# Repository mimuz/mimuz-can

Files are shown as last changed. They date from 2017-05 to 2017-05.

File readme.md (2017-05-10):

# mi:muz:can

mimuz-can logo

`mi:muz-can` and variations are small boards for build easier to midi instrument that sounds cans using with push solenoid.

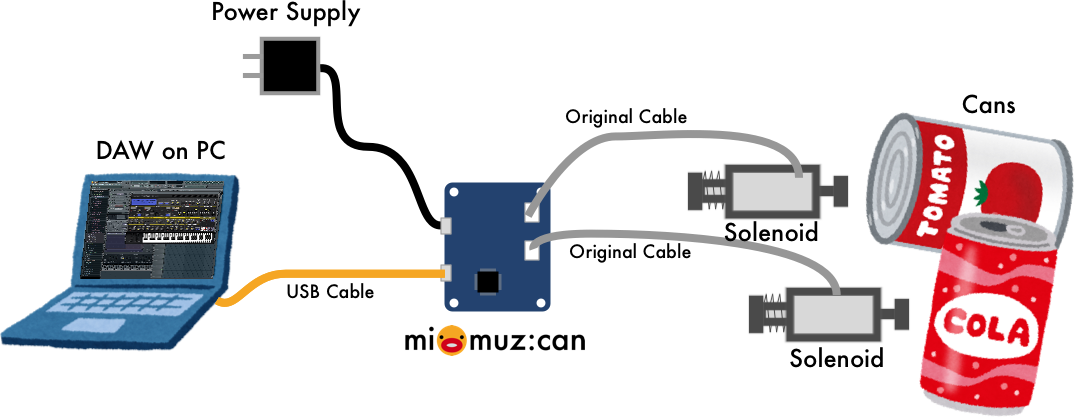
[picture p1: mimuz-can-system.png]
mimuz-can-system


The following variations are exist:

## In Production

- [mi:muz:can (Standard Version)](./mimuz-can): "mi:muz:can" is a board for build easier to USB-MIDI instrument that sounds up to 6 cans using with push solenoid. For using powerful electric current, It has 2.1mm DC Jack for 12V DC Power supply.
- [mi:muz:can-lite](./mimuz-can-lite): "mi:muz:can-lite" is a board for build easier to USB-MIDI instrument that sounds up to 2 cans using with push solenoid. This is a "simple for use" version, It has micro-B usb connector for using USB charger for smartphone/tablet.

## demo

- [1st demo (YouTube)](https://youtu.be/6YQHXj_-I3c)

## Solenoids

All of the mi:muz:can devices are now only support the following 5V PUSH type solenoids:

- [Sparkfun Solenoid - 5v (small) (ROB-11015)](https://www.sparkfun.com/products/11015)
- [ZHO-0420S-05A4.5(5V)](http://akizukidenshi.com/catalog/g/gP-10761/)

## Licenses

- [Licences for mi:muz:can](./mimuz-can/LICENSE.md)
- [Licences for mi:muz:can-lite](./mimuz-can-lite/LICENSE.md)

## [Previous draft versions (Arduino versions)](./draft)

Previous draft versions (Arduino versions) are for experimental use versions made with [Arduino UNO Rev.3](https://store.arduino.cc/arduino-uno-rev3), [Ardiono Leonardo](https://www.arduino.cc/en/main/arduinoBoardLeonardo) and [mi:muz:expr#1](https://github.com/mimuz/mimuz-avr-core/tree/master/boards/expr1).

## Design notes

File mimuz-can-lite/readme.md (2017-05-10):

# mi:muz:can-lite

mimuz-can logo

"mi:muz:can-lite" is a board for build easier to USB-MIDI instrument that sounds up to 2 cans using with push solenoid. This is a "simple for use" version, It has micro-B usb connector for using USB charger for smartphone/tablet.

## Version

- v0.10 (2017.05.10)

## Eagle Files

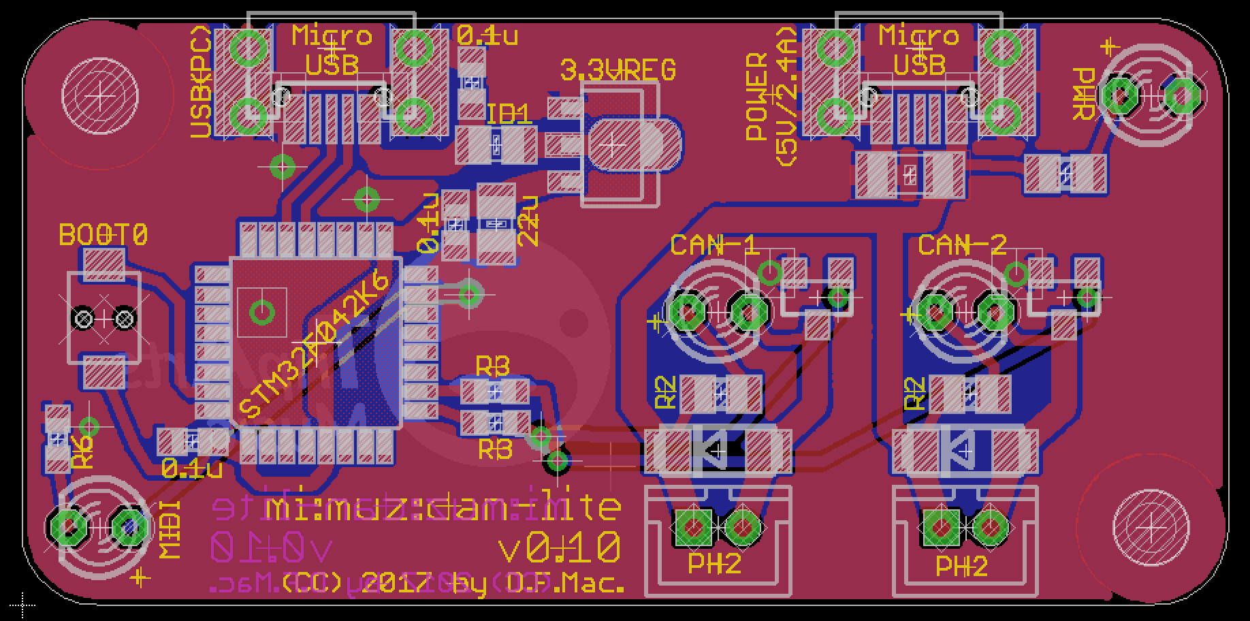
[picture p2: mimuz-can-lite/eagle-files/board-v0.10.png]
board


[eagle files (v0.10)](./eagle-files/v0.10)

## parts

- [STM32F042K6T6](http://www.st.com/content/st_com/ja/products/microcontrollers/stm32-32-bit-arm-cortex-mcus/stm32f0-series/stm32f0x2/stm32f042k6.html) * 1
- [HT7333-A (3.3V regulator) SOT89-3](http://www.holtek.com.tw/documents/10179/116711/HT73xx-1v100.pdf) * 1
- [Ferrite beads (0805)](http://akizukidenshi.com/catalog/g/gP-04054/) * 1 [ID1]
- 470Ω(0603) * 1 (For USB DATA LED)
- 1kΩ(0603) * 2 (For FET gate line)
- 1.5kΩ(0805) * 1 (For Power LED)
- 3mLED * 4 
- 0.1uF(0603) * 3
- 22uF(0805) * 1
- 47uF(1206 25V) * 1
- [Tactical Switch (2 points SMT)](http://www.aitendo.com/product/10525) * 1
- [micro USB Connector](https://www.aliexpress.com/item/Free-shipping-100pcs-lot-4-feet-DIP-5P-SMD-Micro-USB-Connector-V8-Port-Charge-Socket/32214653369.html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) * 2
- PH2.0 2P Connector * 2
- 1N5819(DO214AC SMD) Shotkey diode * 2
- IRLML6344TRPBF SOT23 (Nch Mosfet) * 2

## Firmware

- [Source](../mimuz-can/source)
- [bin](./bin)

### Firmware Setup 

1. Install [SW4STM32](http://www.st.com/content/st_com/ja/products/development-tools/software-development-tools/stm32-software-development-tools/stm32-ides/sw4stm32.html)
2. Install DFU Loader (i.e. dfu-util see [dfu-util - Device Firmware Upgrade Utilities](http://dfu-util.sourceforge.net/))
3. Copy [Source](./source/mimuz-tuch) to your workspace path and select build target `mimuz-can-lite` and Bulding it. When your build process is succeed, `mimuz-can-lite.bin` is created in `./mimuz-can-lite/` folder.
4. push and hold mi:muz:can-lite board switch'BOOT0' switch and connect to USB Port. After connection, you can release switch. `mi:muz:can-lite` board will startup in DFU mode. 
5. Burn [mimuz-can-lite.bin] using DFU Loader. On Mac, enter the following command on terminal in same mimuz-can-lite.bin path.

> `dfu-util -a0 -d 0x0483:0xdf11 -s 0x008000000 -D mimuz-can.bin`

# Licenses

## Hardware (Schematics, Board, Eagle files), Software (Application, USB-MIDI Class Driver)

- [Creative Commons Attribution 4.0 International (CC BY 4.0)](http://creativecommons.org/licenses/by/4.0/)

## Software (STMCube from ST Microsystems)

- 3-clause BSD license

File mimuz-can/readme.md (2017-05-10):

# mi:muz:can (Standard Version)

mimuz-can logo

"mi:muz:can" is a board for build easier to USB-MIDI instrument that sounds up to 6 cans using with push solenoid. For using powerful electric current, It has 2.1mm DC Jack for 12V DC Power supply.

## Version

- v0.30 (2017.05.10)

## Eagle Files

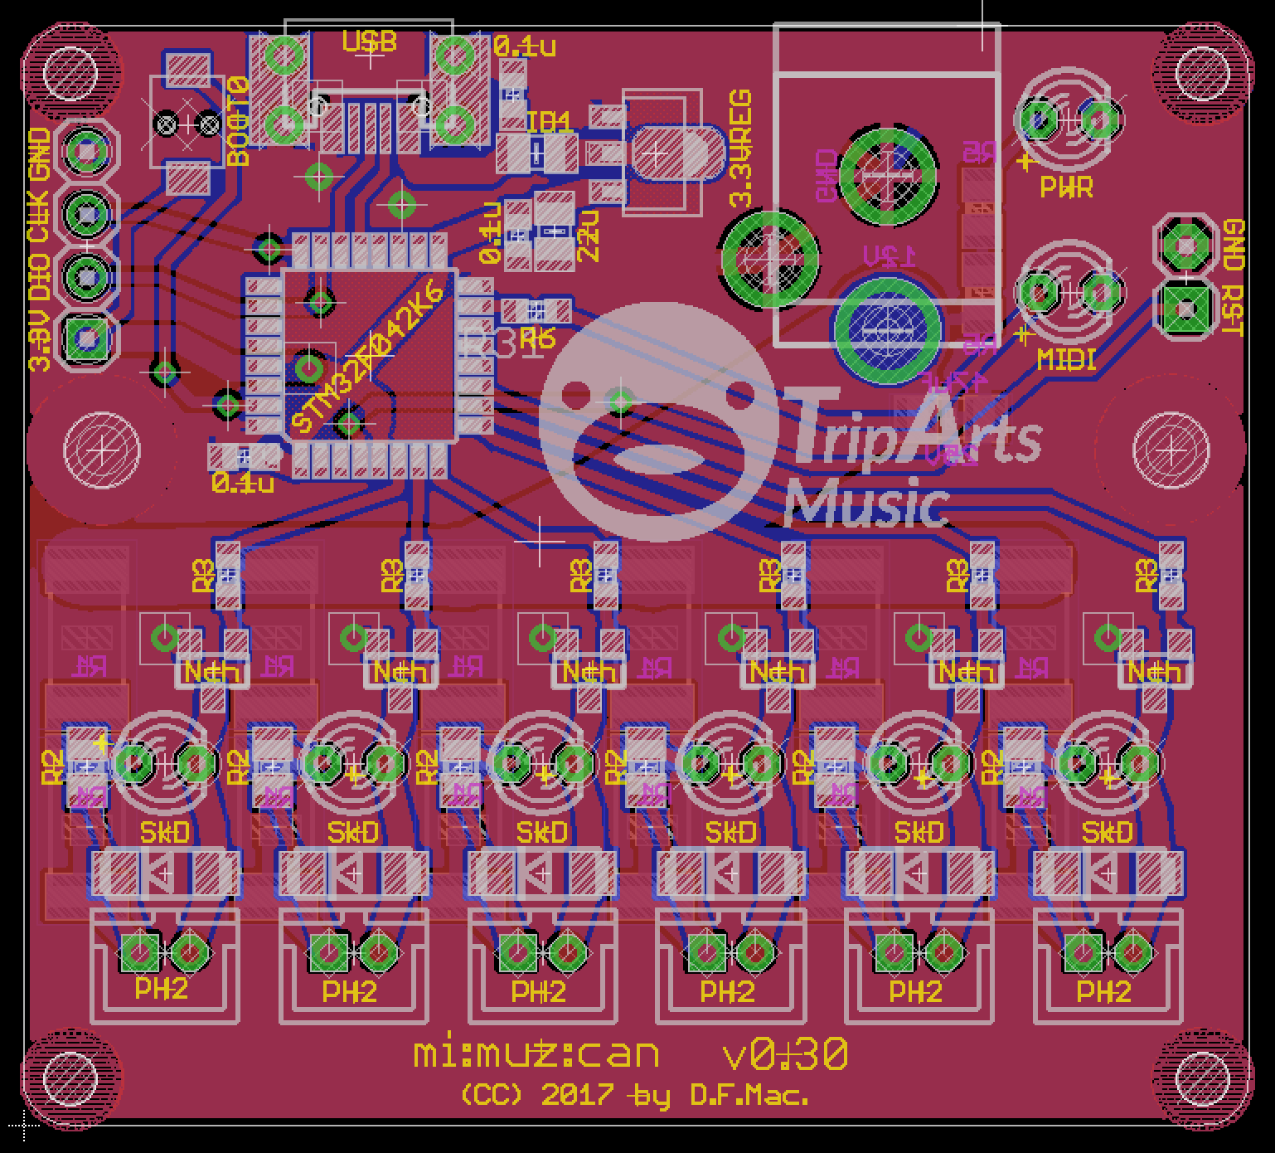
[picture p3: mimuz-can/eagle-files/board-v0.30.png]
board


[eagle files (v0.30)](./eagle-files/v0.30)

## parts

- [STM32F042K6T6](http://www.st.com/content/st_com/ja/products/microcontrollers/stm32-32-bit-arm-cortex-mcus/stm32f0-series/stm32f0x2/stm32f042k6.html) * 1
- [HT7333-A (3.3V regulator) SOT89-3](http://www.holtek.com.tw/documents/10179/116711/HT73xx-1v100.pdf) * 1
- [Ferrite beads (0805)](http://akizukidenshi.com/catalog/g/gP-04054/) * 1 [ID1]
- 470Ω(0603) * 1 (For USB DATA LED)
- 1kΩ(0603) * 6 (For FET gate line)
- 1.5kΩ(0805) * 1 (For Power LED)
- 2.2kΩ(0805) * 1 (For Power LED)
- 8.2Ω(2512 1W) * 12 (For Solenoid Line)
- 3mLED * 8 
- 0.1uF(0603) * 3
- 22uF(0805) * 1
- 47uF(1206 25V) * 1
- [Tactical Switch (2 points SMT)](http://www.aitendo.com/product/10525) * 1
- [micro USB Connector](https://www.aliexpress.com/item/Free-shipping-100pcs-lot-4-feet-DIP-5P-SMD-Micro-USB-Connector-V8-Port-Charge-Socket/32214653369.html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) * 1
- [2.1mm DC Jack](http://akizukidenshi.com/catalog/g/gC-06568/) * 1
- PH2.0 2P Connector * 6
- 1N5819(DO214AC SMD) Shotkey diode * 6
- IRLML6344TRPBF SOT23 (Nch Mosfet) * 6

## Firmware

- [Source](./source)
- [bin](./bin)

### Firmware Setup 

1. Install [SW4STM32](http://www.st.com/content/st_com/ja/products/development-tools/software-development-tools/stm32-software-development-tools/stm32-ides/sw4stm32.html)
2. Install DFU Loader (i.e. dfu-util see [dfu-util - Device Firmware Upgrade Utilities](http://dfu-util.sourceforge.net/))
3. Copy [Source](./source/mimuz-tuch) to your workspace path and select build target `mimuz-can` and Bulding it. When your build process is succeed, `mimuz-can.bin` is created in `./mimuz-can/` folder.
4. push and hold mi:muz:can board switch'BOOT0' switch and connect to USB Port. After connection, you can release switch. `mi:muz:can` board will startup in DFU mode. 
5. Burn [mimuz-can.bin] using DFU Loader. On Mac, enter the following command on terminal in same mimuz-can.bin path.

> `dfu-util -a0 -d 0x0483:0xdf11 -s 0x008000000 -D mimuz-can.bin`

# Licenses

## Hardware (Schematics, Board, Eagle files), Software (Application, USB-MIDI Class Driver)

- [Creative Commons Attribution 4.0 International (CC BY 4.0)](http://creativecommons.org/licenses/by/4.0/)

## Software (STMCube from ST Microsystems)

- 3-clause BSD license

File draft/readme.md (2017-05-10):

# mi:muz:can previous draft versions (Arduino versions)

mimuz-can logo

# 1. mi:muz:expr#1 Version

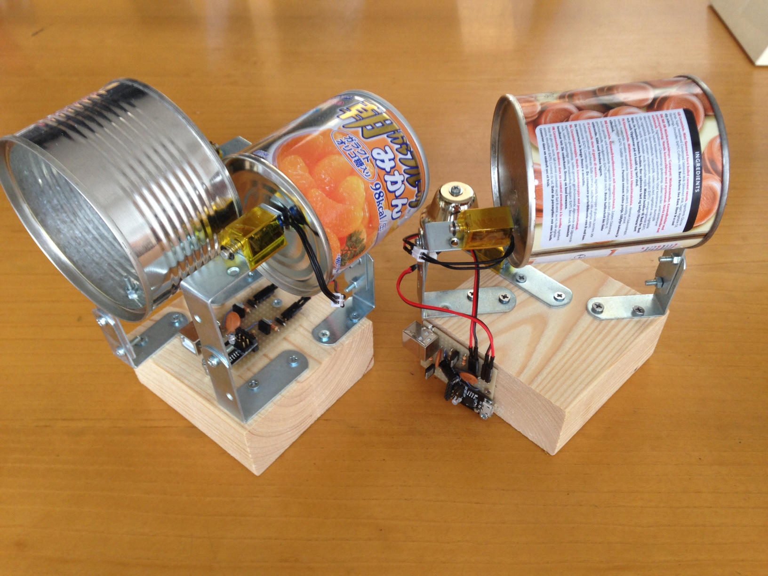
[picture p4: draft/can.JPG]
can attacker


[Maker Faire Tokyo 2015](http://makezine.jp/event/makers2015/d_f_mac_at_triparts_music/)で展示したものです。
[mi:muz:expr#1](https://github.com/tadfmac/mi-muz/tree/master/boards/expr1)ベースで作ったものです。

mi:muz:expr#1は、LEDに利用しているPB3を除くと、PB1とPB4の2つしか空きポートがありません。
これら２つのポートにそれぞれMOSFET、ソレノイドを1つづつ接続して2つの缶を叩くデバイスを作りました。

## Version

v1.0 (2015.08.25)

## Schematics

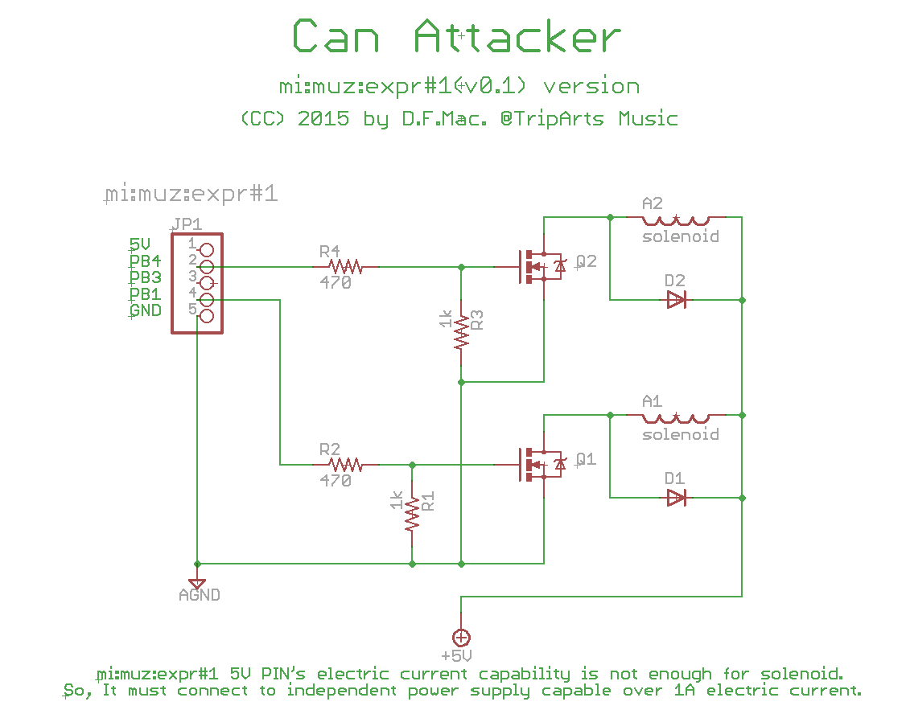
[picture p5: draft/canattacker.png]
can attacker mi:muz:expr#1 version


## parts

- JP1: mi:muz:expr#1
- R1: 1kΩ
- R2: 470Ω
- R3: 1kΩ
- R4: 470KΩ
- Q1/Q2: [2SK4017](http://akizukidenshi.com/catalog/g/gI-07597/)
- D1/D2: 1N4007
- A1/A2: [5V Push Solenoid　ROB-11015](https://www.sparkfun.com/products/11015)

## Firmware

[Firmware](./can1_mimuz-expr1/can1_mimuz-expr1.ino)

# 2. Arduio UNO Version

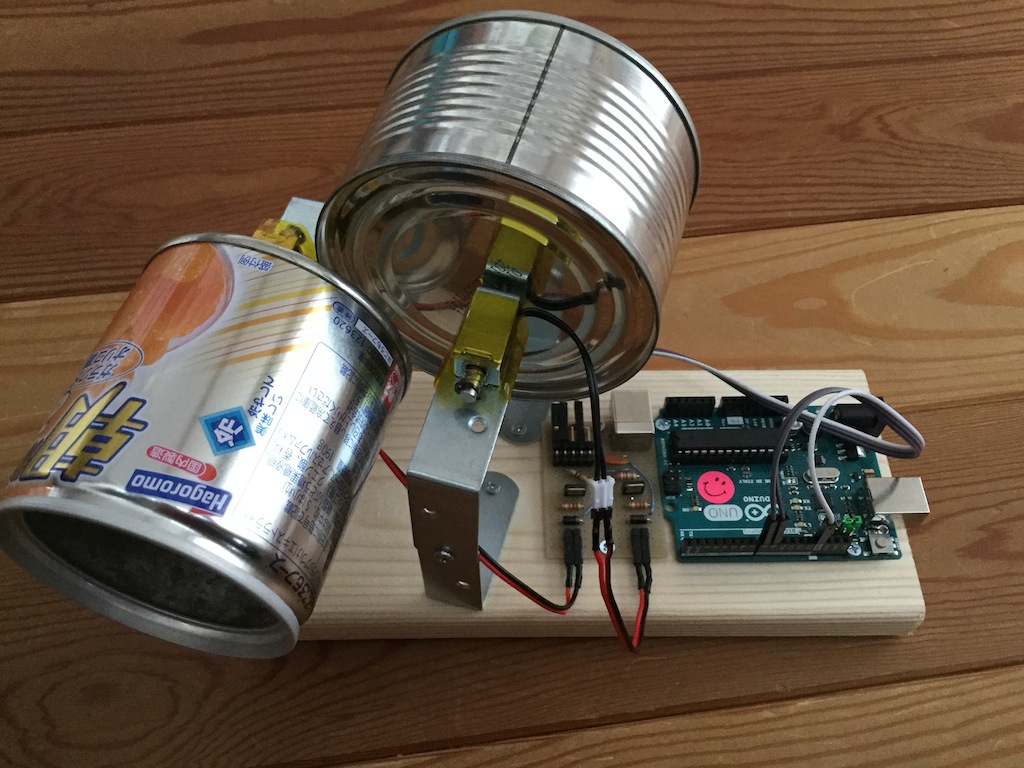
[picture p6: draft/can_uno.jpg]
can attacker Arduino UNO Version


Arduino UNOでも作ってみました。

## Dependencies

Arduino UNOでUSB-MIDIを扱うために、[Arduino MIDI Library](http://playground.arduino.cc/Main/MIDILibrary)と、@morecat_labさん作[mocoLUFA](https://github.com/kuwatay)を利用させて頂いています。

## Version

v1.0 (2015.08.30)

## Schematics

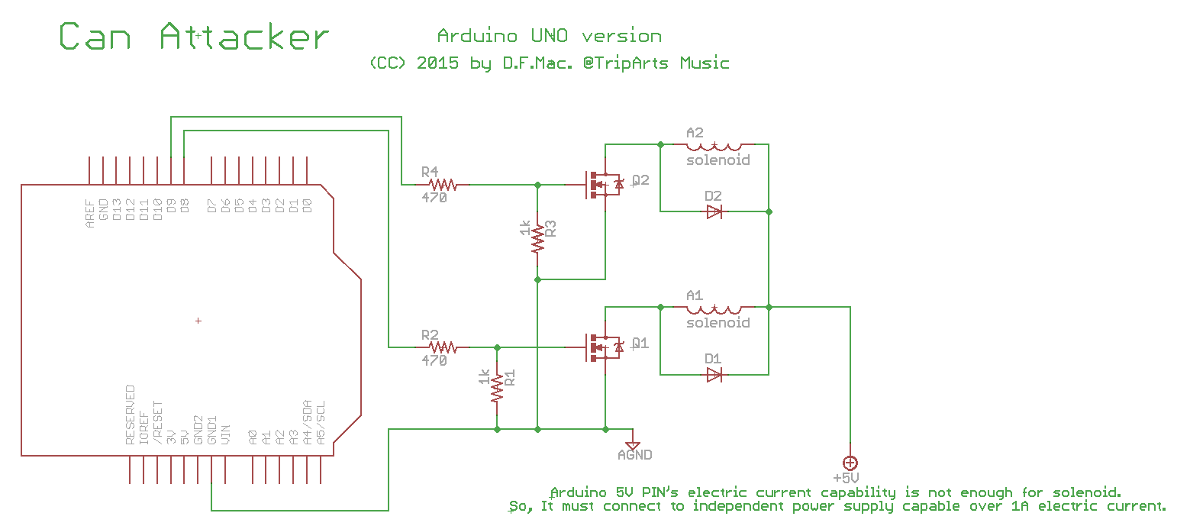
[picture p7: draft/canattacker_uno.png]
can attacker Arduino UNO version


## parts

- Arduino UNO Rev.3
- R1: 1kΩ
- R2: 470Ω
- R3: 1kΩ
- R4: 470KΩ
- Q1/Q2: [2SK4017](http://akizukidenshi.com/catalog/g/gI-07597/)
- D1/D2: 1N4007
- A1/A2: [5V Push Solenoid　ROB-11015](https://www.sparkfun.com/products/11015)

## Firmware

[Firmware](./can2_uno/can2_uno.ino)

----

# 3. Arduino Leonardo Version

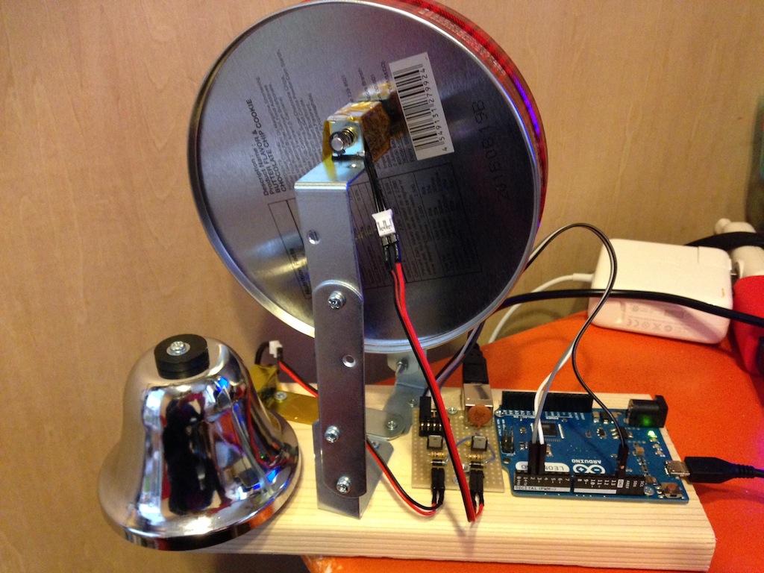
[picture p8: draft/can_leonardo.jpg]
can attacker Arduino Leonardo Version


Arduino Leonardoでも作ってみました！！！！

## Dependencies

Arduino LeonardoをUSB-MIDIに対応させるため、[rkistner/arcore](https://github.com/rkistner/arcore)を利用させて頂きました！

利用方法は、[こちら](http://qiita.com/tadfmac/items/d685dae3e46d570386c3)を参照ください。

## Version

v1.0 (2015.11.25)

## Schematics

配線はArduino UNOバージョンとほぼ同じです。
ただし、下記のように変更しています。

|Arduino UNO Version|Arduino Leonardo Versionでの変更点|
|:----|:---:|
|PIN8|PIN2|
|PIN9|PIN3|

※スケッチがそうなっているというだけで、基本的にお好きなデジタル端子に繋げば大丈夫です。

## parts

- Arduino Leonardo
- R1: 100kΩ (変更してみました)
- R2: 470Ω
- R3: 100kΩ (変更してみました)
- R4: 470KΩ
- Q1/Q2: [IRLU3410PBF](http://akizukidenshi.com/catalog/g/gI-06025/) (2SK4017がどっか行ったので)
- D1/D2: 1N4007
- A1/A2: [5V Push Solenoid　ROB-11015](https://www.sparkfun.com/products/11015)

## Firmware

[Firmware](./can4_leonardo/can4_leonardo.ino)

# Licenses

<br />この 作品 は <a rel="license" href="http://creativecommons.org/licenses/by/4.0/">クリエイティブ・コモンズ 表示 4.0 国際 ライセンスの下に提供されています。</a>

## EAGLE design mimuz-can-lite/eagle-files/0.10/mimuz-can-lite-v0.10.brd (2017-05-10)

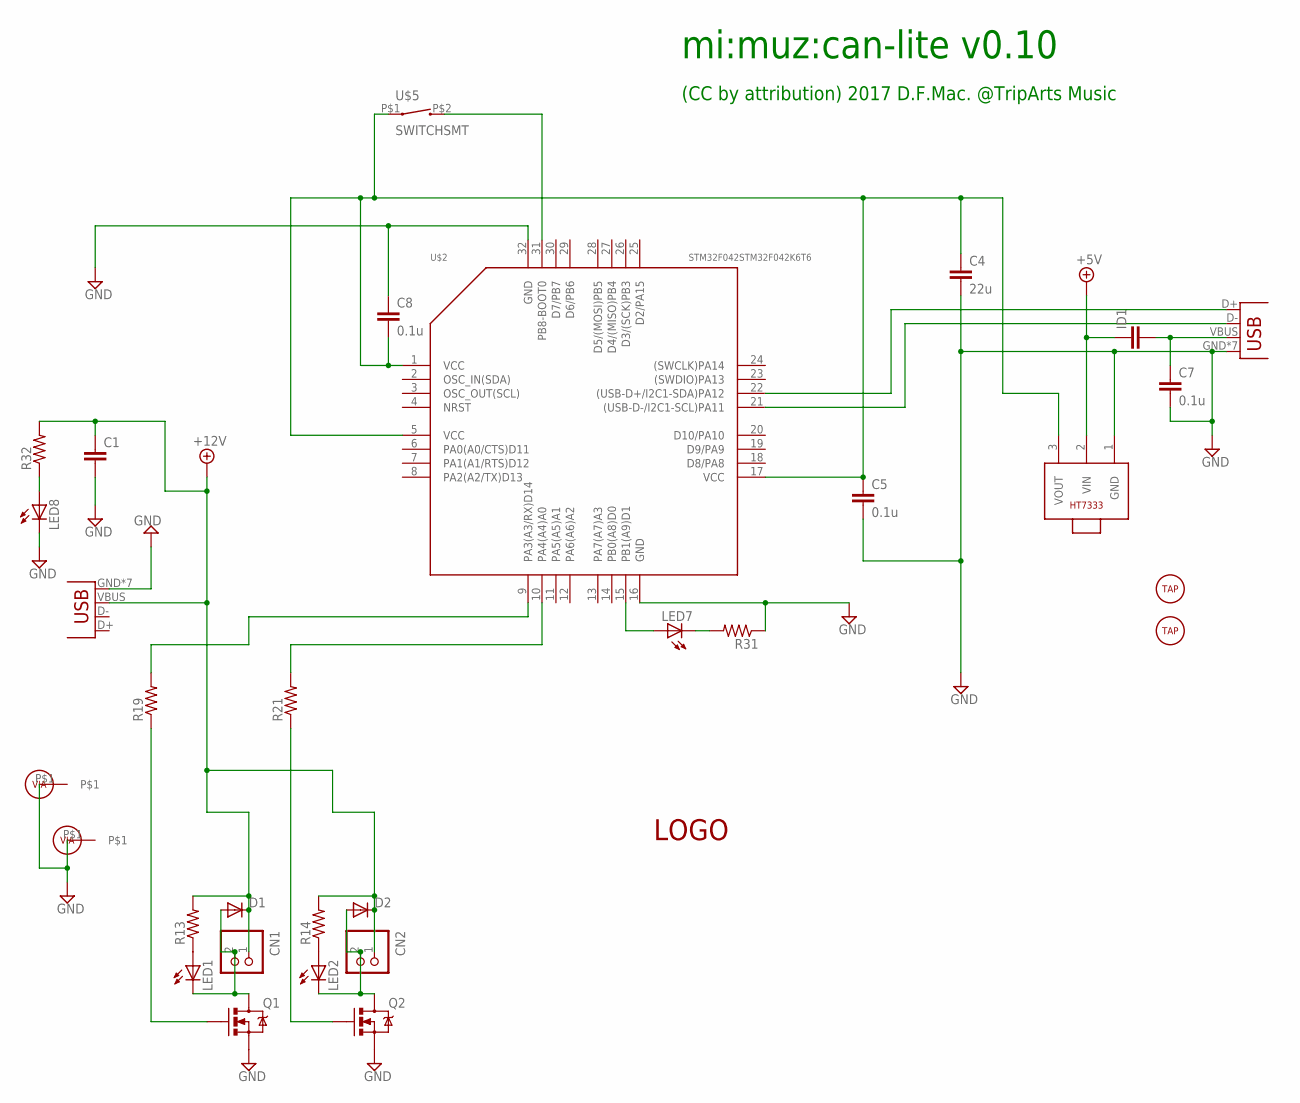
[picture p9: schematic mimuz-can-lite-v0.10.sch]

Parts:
C1: C-EUC1206; C1206
C4: 22u; C0805
C5, C7, C8: 0.1u; C0603
CN1, CN2: B2B-PH-K-S
D1, D2: DIODE-DO214AC; DO214AC
ID1: C-EUC0805; C0805
JP3, JP4: USB-MICROB
LED1, LED2, LED7, LED8: LED3MM
Q1, Q2: MOSFET-NCHANNELSMD; SOT23-3
R13, R14, R32: R-US_R0805; R0805
R19, R21, R31: R-US_R0603; R0603
U$1: LOGOSMALL; LOGO-SMALL
U$2: STM32F042STM32F042K6T6; TQFP32
U$3, U$6: TAPHOLE; TAPHOLE-3MM
U$4, U$7: VIA
U$5: SWITCHSMT; SWITCH-SMT-2*4*3
U$14: HT7333; SOT89

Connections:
3.3V: C4.1, C5.1, C8.2, U$2.1 (VCC), U$2.5 (VCC), U$2.17 (VCC), U$5.P$1 (1), U$14.3 (VOUT)
+5V: ID1.1, U$14.2 (VIN)
+5V2: C1.1, CN1.1, CN2.1, D1.C, D2.C, JP3.VBUS, R13.2, R14.2, R32.2
D+: JP4.D+, U$2.22 ((USB-D+/I2C1-SDA)PA12)
D-: JP4.D-, U$2.21 ((USB-D-/I2C1-SCL)PA11)
GND: C1.2, C4.2, C5.2, C7.2, C8.1, JP3.GND, JP3.MT1 (GND), JP3.MT3 (GND), JP3.P$2 (GND), JP3.P$4 (GND), JP3.P$5 (GND), JP3.P$6 (GND), JP4.GND, JP4.MT1 (GND), JP4.MT3 (GND), JP4.P$2 (GND), JP4.P$4 (GND), JP4.P$5 (GND), JP4.P$6 (GND), LED8.K (C), Q1.2 (S), Q2.2 (S), R31.1, U$2.16 (GND), U$2.32 (GND), U$4.P$1, U$7.P$1, U$14.1 (GND)
unnamed: LED7.A, U$2.15 (PB1(A9)D1)
unnamed: LED7.K (C), R31.2
unnamed: CN1.2, D1.A, LED1.K (C), Q1.3 (D)
unnamed: CN2.2, D2.A, LED2.K (C), Q2.3 (D)
unnamed: LED1.A, R13.1
unnamed: LED2.A, R14.1
unnamed: Q2.1 (G), R21.1
unnamed: Q1.1 (G), R19.1
unnamed: U$2.31 (PB8-BOOT0), U$5.P$2 (2)
unnamed: R19.2, U$2.9 (PA3(A3/RX)D14)
unnamed: R21.2, U$2.10 (PA4(A4)A0)
unnamed: LED8.A, R32.1
VBUS: C7.1, ID1.2, JP4.VBUS

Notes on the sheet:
mi:muz:can-lite v0.10
(CC by attribution) 2017 D.F.Mac. @TripArts Music

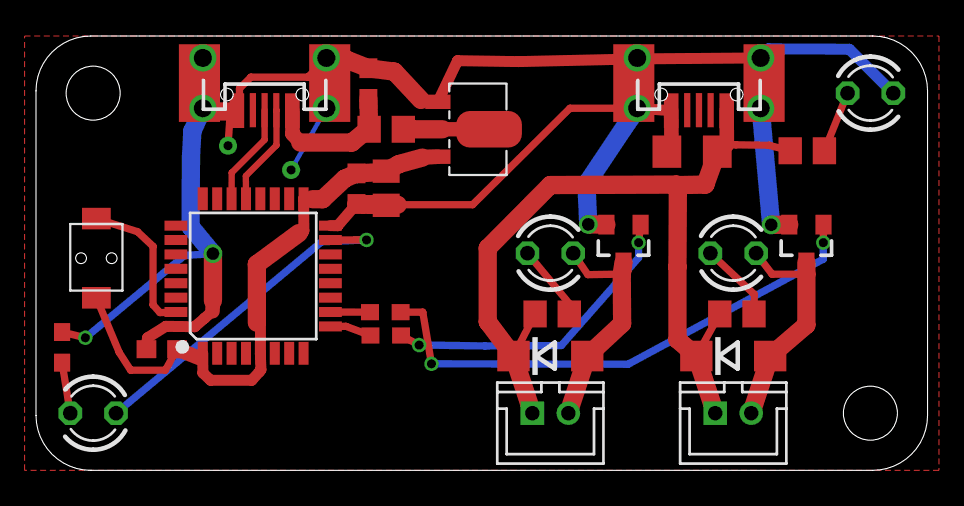
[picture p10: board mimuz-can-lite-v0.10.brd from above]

Board: 2 copper layers, 49.5 x 24.1 mm, 32 parts (1 on the bottom side), 19 nets.

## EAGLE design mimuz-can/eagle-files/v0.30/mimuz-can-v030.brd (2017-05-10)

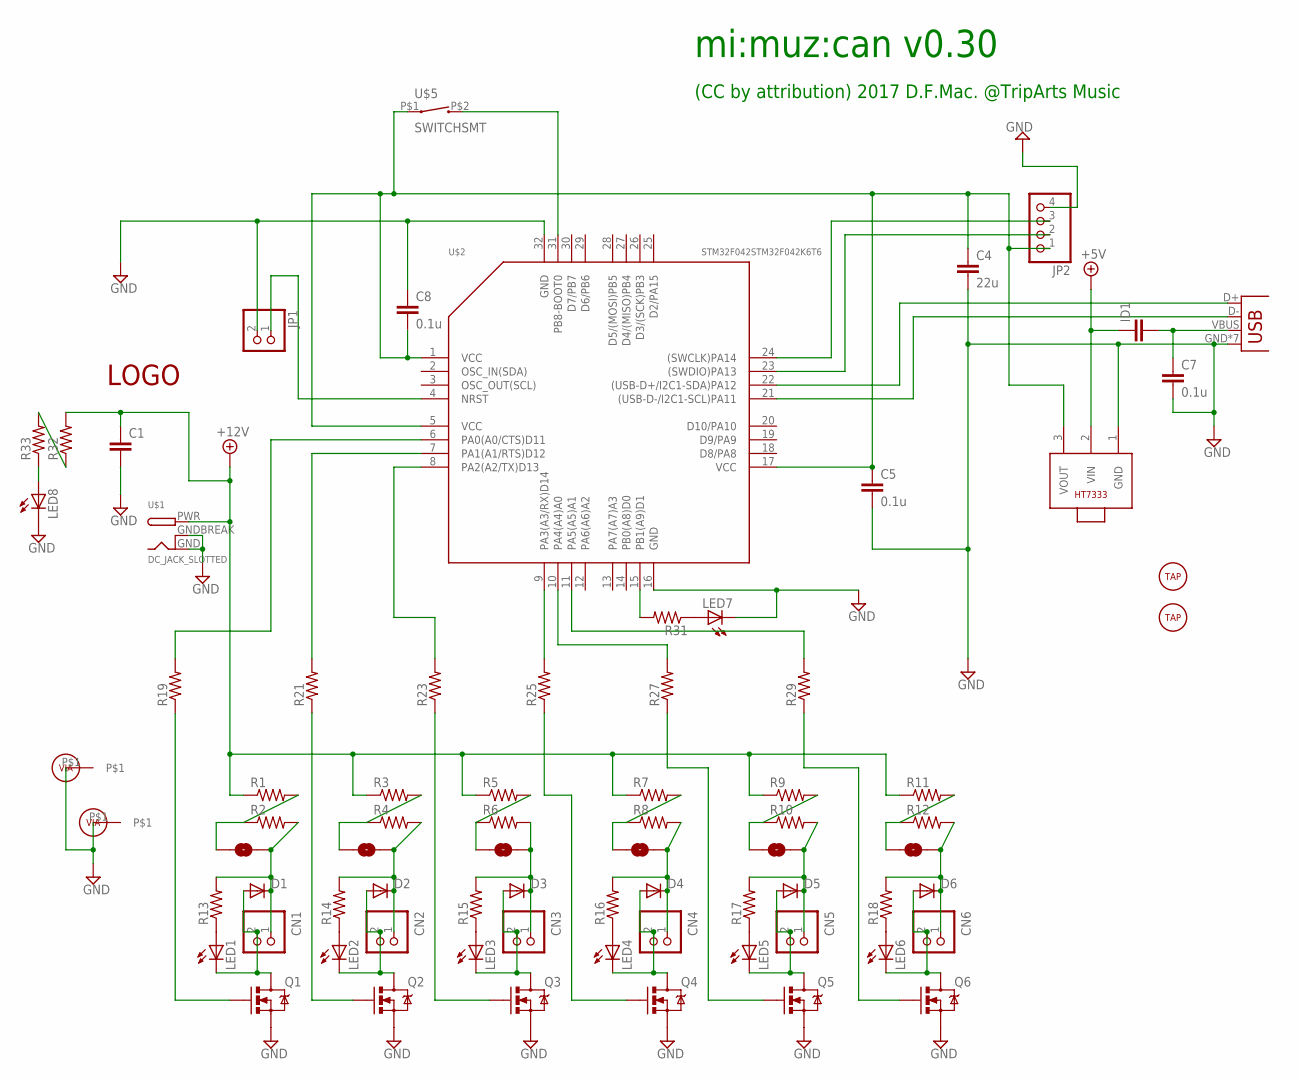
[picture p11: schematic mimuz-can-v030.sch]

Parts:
C1: C-EUC1206; C1206
C4: 22u; C0805
C5, C7, C8: 0.1u; C0603
CN1, CN2, CN3, CN4, CN5, CN6: B2B-PH-K-S
D1, D2, D3, D4, D5, D6: DIODE-DO214AC; DO214AC
ID1: C-EUC0805; C0805
JP1: PINHD-1X2; 1X02
JP2: PINHD-1X4; 1X04
JP3, JP5, JP6, JP7, JP8, JP9: JUMPER-SMT_2_NO_NO-SILK; SMT-JUMPER_2_NO_NO-SILK
JP4: USB-MICROB
LED1, LED2, LED3, LED4, LED5, LED6, LED7, LED8: LED3MM
Q1, Q2, Q3, Q4, Q5, Q6: MOSFET-NCHANNELSMD; SOT23-3
R1, R2, R3, R4, R5, R6, R7, R8, R9, R10, R11, R12: R-US_R2512; R2512
R13, R14, R15, R16, R17, R18, R32, R33: R-US_R0805; R0805
R19, R21, R23, R25, R27, R29, R31: R-US_R0603; R0603
U$1: DC_JACK_SLOTTED
U$2: STM32F042STM32F042K6T6; TQFP32
U$3, U$6: TAPHOLE; TAPHOLE-3MM
U$4, U$7: VIA
U$5: SWITCHSMT; SWITCH-SMT-2*4*3
U$12: LOGOSMALL; LOGO-SMALL
U$14: HT7333; SOT89

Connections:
3.3V: C4.1, C5.1, C8.2, JP2.1, U$2.1 (VCC), U$2.5 (VCC), U$2.17 (VCC), U$5.P$1 (1), U$14.3 (VOUT)
+5V: ID1.1, U$14.2 (VIN)
+12V: C1.1, R1.1, R3.1, R5.1, R7.1, R9.1, R11.1, R32.2, U$1.PWR
D+: JP4.D+, U$2.22 ((USB-D+/I2C1-SDA)PA12)
D-: JP4.D-, U$2.21 ((USB-D-/I2C1-SCL)PA11)
GND: C1.2, C4.2, C5.2, C7.2, C8.1, JP1.2, JP2.4, JP4.GND, JP4.MT1 (GND), JP4.MT3 (GND), JP4.P$2 (GND), JP4.P$4 (GND), JP4.P$5 (GND), JP4.P$6 (GND), LED7.K (C), LED8.K (C), Q1.2 (S), Q2.2 (S), Q3.2 (S), Q4.2 (S), Q5.2 (S), Q6.2 (S), U$1.GND, U$1.GNDBREAK, U$2.16 (GND), U$2.32 (GND), U$4.P$1, U$7.P$1, U$14.1 (GND)
unnamed: JP5.1, R3.2, R4.1
unnamed: JP3.1, R1.2, R2.1
unnamed: JP6.1, R5.2, R6.1
unnamed: CN1.1, D1.C, JP3.2, R2.2, R13.2
unnamed: CN2.1, D2.C, JP5.2, R4.2, R14.2
unnamed: CN3.1, D3.C, JP6.2, R6.2, R15.2
unnamed: CN1.2, D1.A, LED1.K (C), Q1.3 (D)
unnamed: CN2.2, D2.A, LED2.K (C), Q2.3 (D)
unnamed: CN3.2, D3.A, LED3.K (C), Q3.3 (D)
unnamed: JP7.1, R7.2, R8.1
unnamed: CN4.1, D4.C, JP7.2, R8.2, R16.2
unnamed: CN4.2, D4.A, LED4.K (C), Q4.3 (D)
unnamed: CN5.2, D5.A, LED5.K (C), Q5.3 (D)
unnamed: CN6.2, D6.A, LED6.K (C), Q6.3 (D)
unnamed: JP8.1, R9.2, R10.1
unnamed: JP9.1, R11.2, R12.1
unnamed: LED1.A, R13.1
unnamed: CN6.1, D6.C, JP9.2, R12.2, R18.2
unnamed: CN5.1, D5.C, JP8.2, R10.2, R17.2
unnamed: LED2.A, R14.1
unnamed: LED3.A, R15.1
unnamed: LED4.A, R16.1
unnamed: Q2.1 (G), R21.1
unnamed: Q1.1 (G), R19.1
unnamed: LED5.A, R17.1
unnamed: Q3.1 (G), R23.1
unnamed: JP2.3, U$2.24 ((SWCLK)PA14)
unnamed: JP2.2, U$2.23 ((SWDIO)PA13)
unnamed: JP1.1, U$2.4 (NRST)
unnamed: U$2.31 (PB8-BOOT0), U$5.P$2 (2)
unnamed: LED6.A, R18.1
unnamed: R19.2, U$2.6 (PA0(A0/CTS)D11)
unnamed: R21.2, U$2.7 (PA1(A1/RTS)D12)
unnamed: R23.2, U$2.8 (PA2(A2/TX)D13)
unnamed: R27.2, U$2.10 (PA4(A4)A0)
unnamed: R25.2, U$2.9 (PA3(A3/RX)D14)
unnamed: Q4.1 (G), R25.1
unnamed: Q5.1 (G), R27.1
unnamed: R29.2, U$2.11 (PA5(A5)A1)
unnamed: Q6.1 (G), R29.1
unnamed: R31.2, U$2.15 (PB1(A9)D1)
unnamed: LED7.A, R31.1
unnamed: R32.1, R33.2
unnamed: LED8.A, R33.1
VBUS: C7.1, ID1.2, JP4.VBUS

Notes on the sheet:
mi:muz:can v0.30
(CC by attribution) 2017 D.F.Mac. @TripArts Music

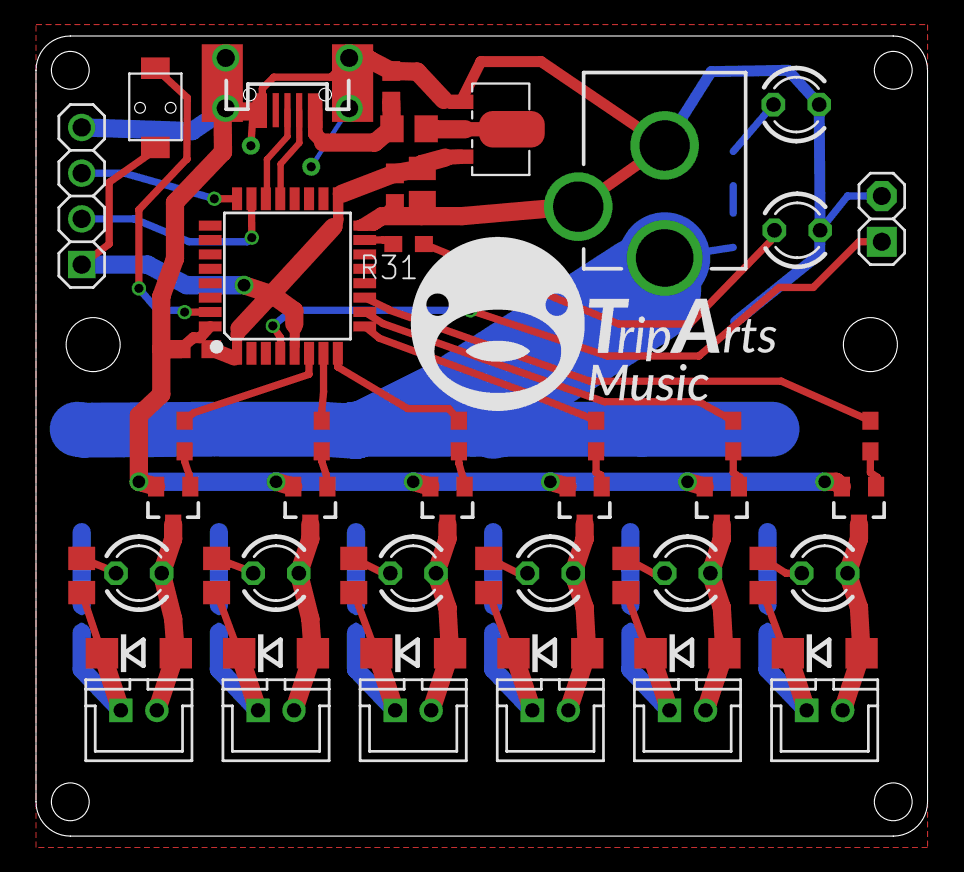
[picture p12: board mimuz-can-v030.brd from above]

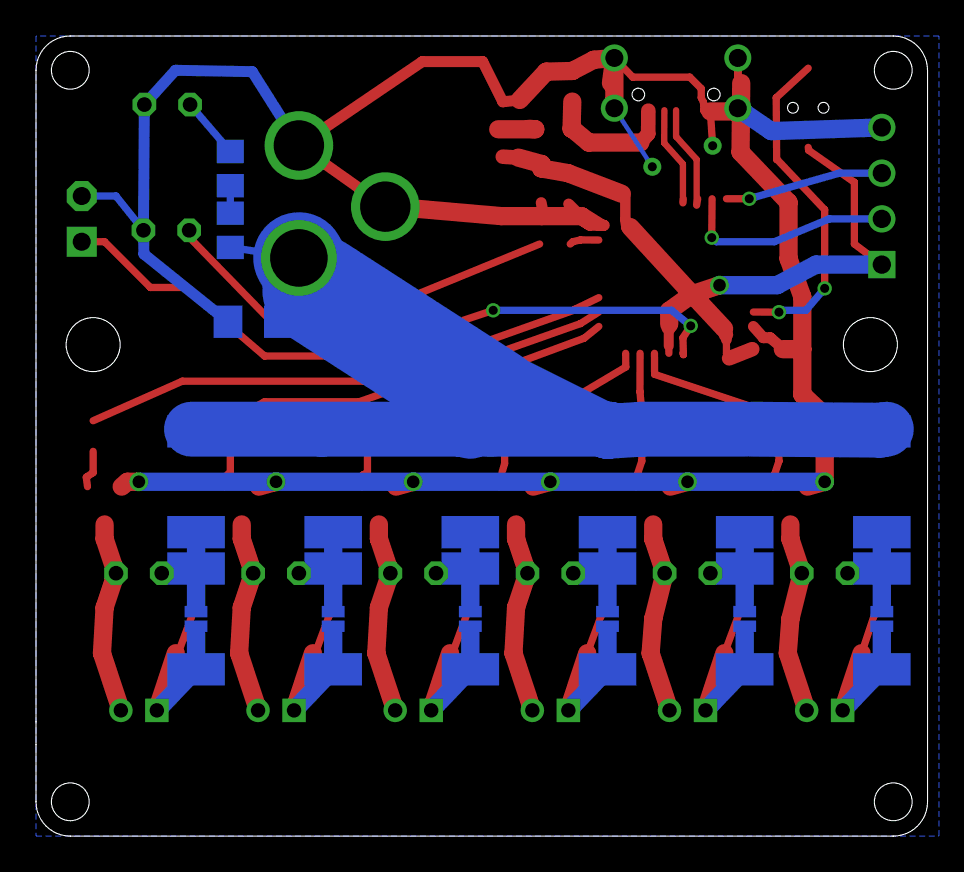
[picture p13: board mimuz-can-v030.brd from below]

Board: 2 copper layers, 49.5 x 44.5 mm, 77 parts (21 on the bottom side), 51 nets.

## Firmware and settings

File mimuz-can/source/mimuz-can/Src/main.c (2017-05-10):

//
// mi:muz:can v0.20
//
//  (CC at)2017 by D.F.Mac. @TripArts Music
//
//
// PIN Configuration
//
// PA0 : CAN OUT #1  (OUT)
// PA1 : CAN OUT #2  (OUT)
// PA2 : CAN OUT #3  (OUT)
// PA3 : CAN OUT #4  (OUT)
// PA4 : CAN OUT #5  (OUT)
// PA5 : CAN OUT #6  (OUT)
// PB1 : LED (OUT)
// PA8 : N/A
// PA9 : N/A
// PA10: N/A
// PA11: USB D-
// PA12: USB D+
// PA13: SWDIO
// PA14: SWCLK
// PA15: N/A
// PB3 : N/A
// PB4 : N/A
// PB5 : N/A
// PB6 : N/A
// PB7 : N/A
// PB8 : BOOT0
// PF0 : N/A
// PF1 : N/A

#include "stm32f0xx_hal.h"
#include "usb_device.h"
#include "usbd_midi_if.h"
#include "eeprom.h"
#include "main.h"

// Can GPIO Table
TCanGPIO tCanGpio[CAN_CHANNELS]={
  {GPIOA, GPIO_PIN_0},
  {GPIOA, GPIO_PIN_1},
  {GPIOA, GPIO_PIN_2},
  {GPIOA, GPIO_PIN_3},
  {GPIOA, GPIO_PIN_4},
  {GPIOA, GPIO_PIN_5} 
};

// EEPROM
uint16_t VirtAddVarTab[NB_OF_VAR] = {
  0x1000, 0x1001, 0x1002, 0x1003,
  0x1004, 0x1005, 0x1006, 0x1007
};

uint16_t VarDataTab[NB_OF_VAR] = {0, 0, 0, 0, 0, 0, 0, 0};

// MIDI
int val[] = {0,0,0,0,0,0};

//uint8_t notes[] = {36,38,40,43,45,48}; // C2 D2 E2 G2 A2 C3
uint8_t notes[] = {60,62,64,67,69,72}; // C4 D4 E4 G4 A4 C5
int onoff[] = {0,0,0,0,0,0};

uint16_t ledTime = 0;

void debug_led(int times){
  int cnt;
  while(1){
    for(cnt = 0;cnt < times;cnt ++){
      HAL_GPIO_WritePin(GPIOB, GPIO_PIN_1, GPIO_PIN_SET);
      HAL_Delay(200);
      HAL_GPIO_WritePin(GPIOB, GPIO_PIN_1, GPIO_PIN_RESET);
      HAL_Delay(200);
    }
    HAL_Delay(1000);
  }
}

int debug_status = 0;


void led_on(void){
  ledTime = LEDTIMEMAX;
  HAL_GPIO_WritePin(GPIOB, GPIO_PIN_1, GPIO_PIN_SET);
}

void led_off(void){
  ledTime = 0;
  HAL_GPIO_WritePin(GPIOB, GPIO_PIN_1, GPIO_PIN_RESET);
}

static void onNoteOn(uint8_t ch, uint8_t note, uint8_t vel){
  int canNumber;
  led_on();

  canNumber = getNoteCh(note);
  if(canNumber != -1){
	  if(vel != 0){
	    onoff[canNumber] = CAN_TIMEBASE + (CAN_TIMESTEP * vel);
	    CanStart(canNumber);
	  }
  }
}

static void onNoteOff(uint8_t ch, uint8_t note, uint8_t vel){
}


static int getNoteCh(uint8_t noteNum){
  int cnt;
  for(cnt=0;cnt<CAN_CHANNELS;cnt++){
    if(notes[cnt] == noteNum){
      return cnt;
    }
  }
  return -1;
}

uint8_t mode = 0; // 0: none 1: write 2: read

static void onCtlChange(uint8_t ch, uint8_t num, uint8_t value){
  uint8_t func;

  led_on();
  if(ch == 15){
    func = num - 110;
    if(func == 9){        // 119
      mode = value;
    }else if(func < 6){  // Preset-number 110-115
      if(mode == 1){
        EE_WriteVariable(VirtAddVarTab[func],value);
        notes[func] = value;
      }else{  // mode == 2
        sendCtlChange(15,119,1);
        processMidiMessage();
        sendCtlChange(15,num,notes[func]);
        processMidiMessage();
      }
      mode = 0;
    }
  }
}

void loadNums(){
  uint8_t cnt;
  uint8_t cntmax = CAN_CHANNELS; // note numbers
  uint16_t chk;
  chk = EE_ReadVariable(VirtAddVarTab[7],&VarDataTab[7]);
  if(chk == 0){
    for(cnt = 0;cnt < cntmax;cnt ++){
      EE_ReadVariable(VirtAddVarTab[cnt],&VarDataTab[cnt]);
      notes[cnt] = (uint8_t)VarDataTab[cnt];
    }
  }else{
    for(cnt = 0;cnt < cntmax;cnt ++){
      EE_WriteVariable(VirtAddVarTab[cnt],(uint16_t)(notes[cnt]));
    }
    EE_WriteVariable(VirtAddVarTab[7],8);
  }
}


void CanStart(int ch){
  HAL_GPIO_WritePin(tCanGpio[ch].pOutGPIOPort, tCanGpio[ch].OutPin, GPIO_PIN_SET);
}

void CanEnd(int ch){
  HAL_GPIO_WritePin(tCanGpio[ch].pOutGPIOPort, tCanGpio[ch].OutPin, GPIO_PIN_RESET);
}

int old_button = GPIO_PIN_RESET;


void trigNoteOff(){
  int cnt;

  for(cnt=0;cnt<CAN_CHANNELS;cnt++){
    if(onoff[cnt] > 0){
      onoff[cnt] --;
      if(onoff[cnt] == 0){
        CanEnd(cnt);
      }
    }
  }

  if(ledTime > 0){
    ledTime --;
    if(ledTime == 0){
      led_off();
    }
  }


}

int main(void){
  HAL_Init();
  SystemClock_Config();
  MX_GPIO_Init();

  HAL_GPIO_WritePin(GPIOB, GPIO_PIN_1, GPIO_PIN_SET);
  HAL_Delay(200);
  HAL_GPIO_WritePin(GPIOB, GPIO_PIN_1, GPIO_PIN_RESET);
  HAL_Delay(200);
  HAL_GPIO_WritePin(GPIOB, GPIO_PIN_1, GPIO_PIN_SET);
  HAL_Delay(200);
  HAL_GPIO_WritePin(GPIOB, GPIO_PIN_1, GPIO_PIN_RESET);
  HAL_Delay(600);

  MX_USB_DEVICE_Init();
  HAL_FLASH_Unlock();

  EE_Init();
  loadNums();

  // mimuz
  mimuz_init();
  setHdlNoteOff(onNoteOff);
  setHdlNoteOn(onNoteOn);
  setHdlCtlChange(onCtlChange);

  while (1){
    processMidiMessage();
    trigNoteOff();

/*
    if(debug_status == 0){
      debug_led(debug_status);
    }
*/
//    HAL_Delay(WAIT_TIME_MS);

  }
}

void SystemClock_Config(void)
{
  RCC_OscInitTypeDef RCC_OscInitStruct;
  RCC_ClkInitTypeDef RCC_ClkInitStruct;

  RCC_PeriphCLKInitTypeDef PeriphClkInit;

  RCC_OscInitStruct.OscillatorType = RCC_OSCILLATORTYPE_HSI48;
  RCC_OscInitStruct.HSI48State = RCC_HSI48_ON;
  RCC_OscInitStruct.PLL.PLLState = RCC_PLL_ON;
  RCC_OscInitStruct.PLL.PLLSource = RCC_PLLSOURCE_HSI48;
  RCC_OscInitStruct.PLL.PREDIV = RCC_PREDIV_DIV2;
  RCC_OscInitStruct.PLL.PLLMUL = RCC_PLL_MUL2;

  if (HAL_RCC_OscConfig(&RCC_OscInitStruct) != HAL_OK)
  {
    Error_Handler(4);
  }

  RCC_ClkInitStruct.ClockType = RCC_CLOCKTYPE_HCLK|RCC_CLOCKTYPE_SYSCLK|RCC_CLOCKTYPE_PCLK1;
  RCC_ClkInitStruct.SYSCLKSource = RCC_SYSCLKSOURCE_PLLCLK;
  RCC_ClkInitStruct.AHBCLKDivider = RCC_SYSCLK_DIV1;
  RCC_ClkInitStruct.APB1CLKDivider = RCC_HCLK_DIV1;
  if (HAL_RCC_ClockConfig(&RCC_ClkInitStruct, FLASH_LATENCY_1) != HAL_OK)
  {
    Error_Handler(5);
  }

  PeriphClkInit.PeriphClockSelection = RCC_PERIPHCLK_USB;
  PeriphClkInit.UsbClockSelection = RCC_USBCLKSOURCE_HSI48;
  if (HAL_RCCEx_PeriphCLKConfig(&PeriphClkInit) != HAL_OK)
  {
    Error_Handler(6);
  }

  HAL_SYSTICK_Config(HAL_RCC_GetHCLKFreq()/1000);
  HAL_SYSTICK_CLKSourceConfig(SYSTICK_CLKSOURCE_HCLK);
  HAL_NVIC_SetPriority(SysTick_IRQn, 0, 0);
}


// PA0 : CAN OUT #1  (OUT)
// PA1 : CAN OUT #2  (OUT)
// PA2 : CAN OUT #3  (OUT)
// PA3 : CAN OUT #4  (OUT)
// PA4 : CAN OUT #5  (OUT)
// PA5 : CAN OUT #6  (OUT)
// PB1 : LED (OUT)

static void MX_GPIO_Init(void){
  GPIO_InitTypeDef GPIO_InitStruct;

  /* GPIO Ports Clock Enable */
  __HAL_RCC_GPIOA_CLK_ENABLE();
  __HAL_RCC_GPIOB_CLK_ENABLE();

  /*Configure GPIO pin Output Level */
  HAL_GPIO_WritePin(GPIOA, GPIO_PIN_0|GPIO_PIN_1|GPIO_PIN_2|GPIO_PIN_3|GPIO_PIN_4|GPIO_PIN_5,GPIO_PIN_RESET);

  /*Configure GPIO pin Output Level */
  HAL_GPIO_WritePin(GPIOB, GPIO_PIN_1, GPIO_PIN_RESET);

  /*Configure GPIO pins : PA0 PA1 PA2 PA3 PA4 PA5 */ 
  GPIO_InitStruct.Pin = GPIO_PIN_0|GPIO_PIN_1|GPIO_PIN_2|GPIO_PIN_3|GPIO_PIN_4|GPIO_PIN_5;
  GPIO_InitStruct.Mode = GPIO_MODE_OUTPUT_PP;
  GPIO_InitStruct.Pull = GPIO_NOPULL;
  GPIO_InitStruct.Speed = GPIO_SPEED_FREQ_LOW;
  HAL_GPIO_Init(GPIOA, &GPIO_InitStruct);

  /*Configure GPIO pins : PB1 */
  GPIO_InitStruct.Pin = GPIO_PIN_1;
  GPIO_InitStruct.Mode = GPIO_MODE_OUTPUT_PP;
  GPIO_InitStruct.Pull = GPIO_NOPULL;
  GPIO_InitStruct.Speed = GPIO_SPEED_FREQ_LOW;
  HAL_GPIO_Init(GPIOB, &GPIO_InitStruct);
}

void Error_Handler(int num){
  sendCtlChange(15,4,num); // debug
  led_on();
  while(1){
  }
}

#ifdef USE_FULL_ASSERT
void assert_failed(uint8_t* file, uint32_t line){}
#endif

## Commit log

2017-05-10 add mi:muz:can files
    [mimuz-can-v030.brd, mimuz-can-v030.sch]
2017-05-10 add mi:muz:can-lite files
    [mimuz-can-lite-v0.10.brd, mimuz-can-lite-v0.10.sch]

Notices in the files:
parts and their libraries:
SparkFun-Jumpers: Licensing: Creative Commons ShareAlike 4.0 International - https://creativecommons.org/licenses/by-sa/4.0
